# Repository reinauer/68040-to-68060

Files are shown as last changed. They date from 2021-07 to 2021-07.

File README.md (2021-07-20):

# 68040-to-68060

This is a 68040 to 68060 adapter. It allows you to physically connect
a 68060 CPU to any CPU socket that fits a 68040 CPU, assuming there
is enough physical clearance.

## About

This work is a derivative of the 68040 to 68060 adapter
by richx which in turn is based on a 2013 design from
the a1k.org forum.

At the time of this writing, the original kicad project
can be found at https://eab.abime.net/showthread.php?t=100942

The differences between this design and the original KiCAD
version are:

  - Moved the inner 4-pin connector in line with the substrate
    and the pins of the PGA socket. This allows to use sockets
    with 5 rows of pins without using a dremel.
  - Move the capacitors a bit more to the center to make space
    for 5 pin row sockets.
  - use 0603 4.7k resistor networks instead of 0805 resistors to
    clean up the space and have fewer parts to solder
  - move all three diodes in line for easier soldering

## Assembly

The two PCBs need to be separated before assembly.

It is possible to build these with 0.1" pitch breakaway female
pin headers. However, is is much easier to solder full PGA sockets.
The top one has 206 pins, the bottom one 179. That is a large number
of breakaway pins if you go down that route.

'NOTE:' The bottom of the top PCBs has circles around some of the
pins. These are carrying VCC and must not make contact to the bottom
PCB or you will operate your 68060 at 5V instead of 3.3V. You might
destroy your processor this way, so be careful.

During assembly, you have the choice to either cut those pins, or you
can use an intermediate socket with those pins removed. This will increase
the height of your adapter by a few mm and increase the price because
you will need a third PGA socket, but make the assembly process a lot
cleaner and more reproducible.

Further reading on my adventures building these:
* [68040 to 68060 – Upformation](https://amiga.technology/2021/01/18/68040-to-68060-upformation/)
* [Finding common GND](https://amiga.technology/2021/02/25/finding-common-gnd/)
* [All good things](https://amiga.technology/2021/03/21/all-good-things/)

## Bill of Materials

Here's the [Bill of Materials (BOM)](https://htmlpreview.github.io/?https://raw.githubusercontent.com/reinauer/68040-to-68060/main/bom.html).

## Make your own

* [PCBWay](https://www.pcbway.com/project/shareproject/68040_to_68060_adapter.html)
* [OSHpark](https://oshpark.com/shared_projects/q8HjYPrh)

## Credits

Big thank you goes to richx, who did the original KiCAD version
and to Mozart, Lemmy and Matze from the a1k.org forum for the
Eagle version before that.

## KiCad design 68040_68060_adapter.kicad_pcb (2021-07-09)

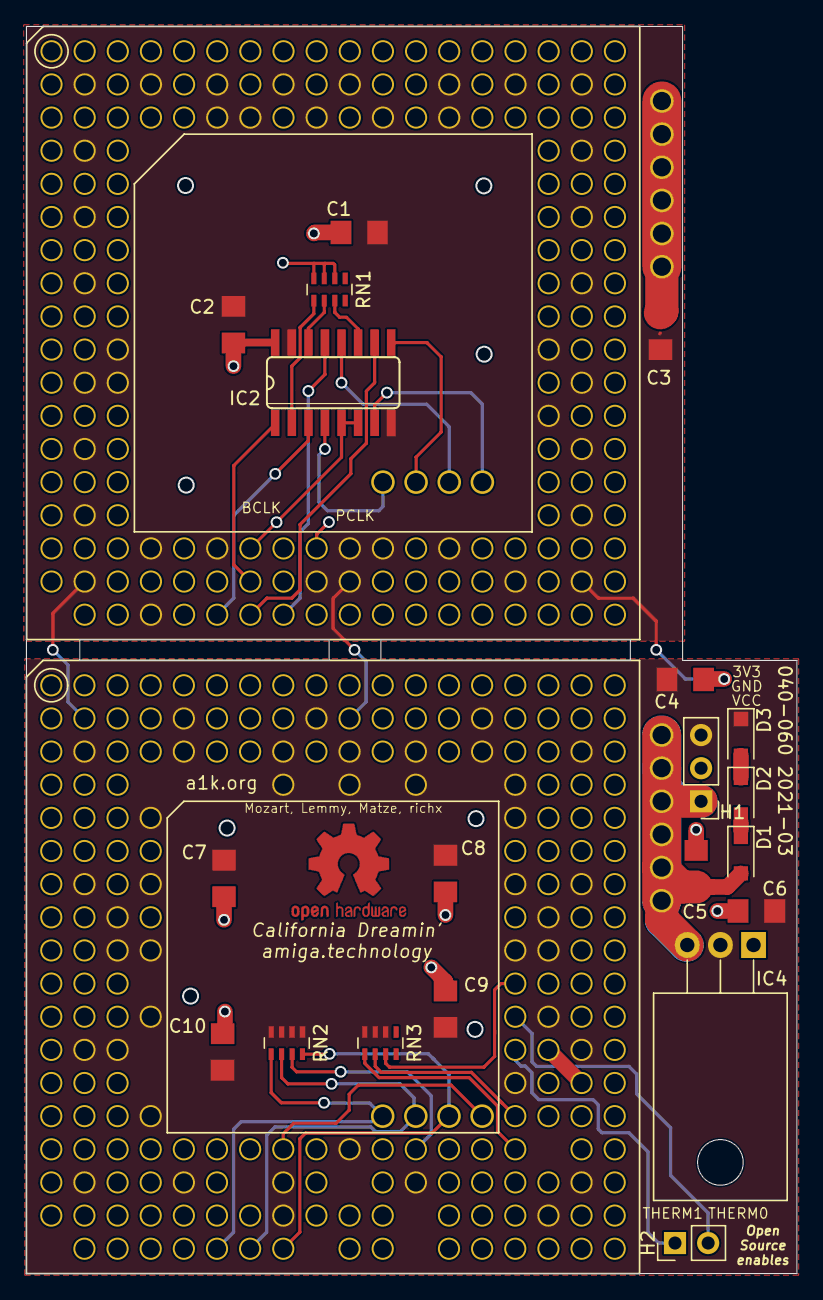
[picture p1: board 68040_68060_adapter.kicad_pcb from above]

Board: 2 copper layers, 59.1 x 95.6 mm, 26 parts (0 on the bottom side), 28 nets.

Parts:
C1, C4: 10u; C1206
C2, C3, C5, C6, C7, C8, C9, C10: 100n; C1206
D1, D2, D3: 1N4001; D_SOD-123F
H1: Power; PinHeader_1x03_P2.54mm_Vertical
H2: Therm; PinHeader_1x02_P2.54mm_Vertical
IC1: PGA179_BIG
IC2: 74F257; SO16
IC3: MC68060RCPGA_BIG; PGA206_BIG
IC4: LMS1585-3.3; TO-220-3_Horizontal_TabDown
RN1: 4.7K; R_Array_Concave_4x0603
RN2, RN3: 4.7k; R_Array_Concave_4x0603
U4$1, U4$1#2: 4POL; 4-PIN-1.4HOLES
U6$1, U6$1#2: 6POL; 6-PIN-1.4HOLES

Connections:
40_BCLK: IC1.R07, IC2.5, IC2.6
40_IPL0: IC1.T08, IC2.13
40_IPL1: IC1.T07, IC2.10
40_IPL2: IC1.T06, IC2.3
40_RSTI: IC1.S07, IC2.1
60_CLKEN: IC2.7, U4$1.P4$1
60_IPL0: IC2.12, U4$1.P4$2
60_IPL1: IC2.9, U4$1.P4$3
60_IPL2: IC2.4, U4$1.P4$4
+3V3: C4.1, C6.1, C7.1, C8.1, C9.1, C10.1, D3.1, H1.3, IC3.B05, IC3.B09, IC3.B14, IC3.C02, IC3.C05, IC3.C08, IC3.C10, IC3.C12, IC3.C14, IC3.C17, IC3.D08, IC3.D10, IC3.D12, IC3.D15, IC3.E04, IC3.E15, IC3.G02, IC3.G04, IC3.G15, IC3.G17, IC3.H03, IC3.H16, IC3.J03, IC3.J04, IC3.J15, IC3.J16, IC3.L04, IC3.L16, IC3.M02, IC3.M03, IC3.M17, IC3.N15, IC3.P04, IC3.Q10, IC3.R02, IC3.R05, IC3.R08, IC3.R12, IC3.R17, IC3.S08, IC3.S16, IC4.2, RN2.1, RN2.2, RN2.3, RN2.4, RN3.2, RN3.3, RN3.4
BTT: IC3.Q15, RN3.5
CLA: IC3.K15, RN3.7
CLKEN: IC3.Q08, U4$1#2.P4$1
GND: C1.2, C2.2, C3.2, C4.2, C5.2, C6.2, C7.2, C8.2, C9.2, C10.2, H1.2, IC1.B02, IC1.B04, IC1.B06, IC1.B08, IC1.B10, IC1.B13, IC1.B15, IC1.B17, IC1.C06, IC1.C07, IC1.C09, IC1.C11, IC1.C13, IC1.D02, IC1.D17, IC1.F02, IC1.F17, IC1.H02, IC1.H17, IC1.K03, IC1.K16, IC1.L02, IC1.L03, IC1.L17, IC1.M16, IC1.N02, IC1.N17, IC1.Q02, IC1.Q17, IC1.R04, IC1.R06, IC1.R10, IC1.R11, IC1.R13, IC1.S02, IC1.S09, IC1.S10, IC1.S15, IC1.S17, IC1.T04, IC2.8, IC2.15, IC3.B02, IC3.B04, IC3.B06, IC3.B08, IC3.B10, IC3.B13, IC3.B15, IC3.B17, IC3.C06, IC3.C07, IC3.C09, IC3.C11, IC3.C13, IC3.D02, IC3.D17, IC3.F02, IC3.F04, IC3.F15, IC3.F17, IC3.H02, IC3.H04, IC3.H15, IC3.H17, IC3.K03, IC3.K16, IC3.L02, IC3.L03, IC3.L17, IC3.M16, IC3.N02, IC3.N17, IC3.Q02, IC3.Q09, IC3.Q11, IC3.Q17, IC3.R04, IC3.R06, IC3.R11, IC3.R13, IC3.S02, IC3.S09, IC3.S10, IC3.S15, IC3.S17, IC4.1
IPL0: IC3.T08, RN2.8, U4$1#2.P4$2
IPL1: IC3.T07, RN2.6, U4$1#2.P4$3
IPL2: IC3.T06, RN2.5, U4$1#2.P4$4
unnamed: IC2.2, RN1.5
unnamed: IC2.11, RN1.7
unnamed: IC2.14, RN1.6
ND1: D1.1, D2.2
ND2: D2.1, D3.2
SNOOP: IC3.P15, RN3.6
THERM0: H2.2, IC3.L15
THERM1: H2.1, IC3.M15
TRA: IC3.Q12, RN2.7
VCC: C1.1, C2.1, C3.1, IC1.B05, IC1.B09, IC1.B14, IC1.C02, IC1.C05, IC1.C08, IC1.C10, IC1.C12, IC1.C14, IC1.C17, IC1.G02, IC1.G17, IC1.H03, IC1.H16, IC1.J03, IC1.J16, IC1.L16, IC1.M02, IC1.M03, IC1.M17, IC1.R02, IC1.R05, IC1.R08, IC1.R12, IC1.R17, IC1.S08, IC1.S16, IC2.16, RN1.2, RN1.3, RN1.4, U6$1#2.P6$1, U6$1#2.P6$2, U6$1#2.P6$3, U6$1#2.P6$4, U6$1#2.P6$5, U6$1#2.P6$6
VCC2: C5.1, D1.2, H1.1, IC4.3, U6$1.P6$1, U6$1.P6$2, U6$1.P6$3, U6$1.P6$4, U6$1.P6$5, U6$1.P6$6

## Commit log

2021-03-14 Original version by richx
    https://eab.abime.net/showthread.php?t=100942
    [68040_68060_adapter.kicad_pcb]
2021-03-14 Updated version 03-2021
    - move inner connector in line with substrate
    and the pins of the socket. This allows to use sockets
    with 5 rows of pins without using a dremel
    - move capacitors a bit more to the center to make space
    for 5 pin row sockets.
    - use 0603 4.7k resistor networks instead of 0805 resistors
    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
    [68040_68060_adapter.kicad_pcb]
2021-03-16 Add interactive BOM and update README
    Made a BOM with https://github.com/openscopeproject/InteractiveHtmlBom
    and improved the README based on feedback.
2021-03-16 Fix BOM link
    Using htmlpreview.github.io is the way to go.
2021-07-09 Properly connect IPL2
    [68040_68060_adapter.kicad_pcb]
